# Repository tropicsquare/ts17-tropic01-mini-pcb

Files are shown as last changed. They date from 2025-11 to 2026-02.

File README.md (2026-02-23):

# TROPIC01 mini

This repository contains design files for the TROPIC01 minimal integration board TS17xx.
The ultimately small board for any purpose. Just control pins with power pins and that’s it. 

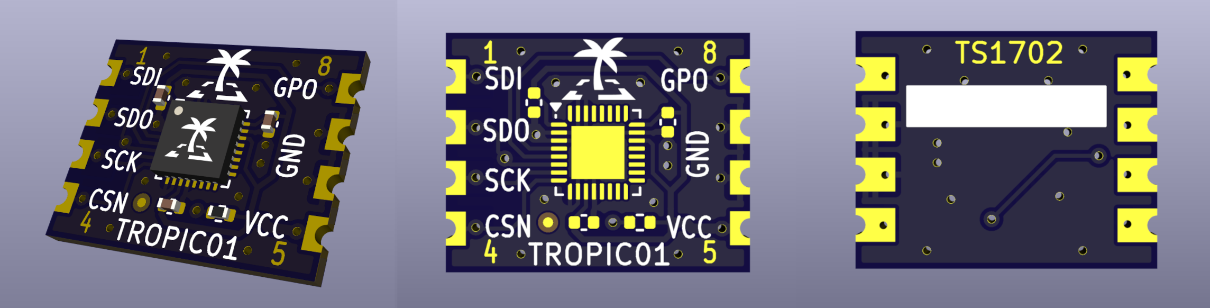
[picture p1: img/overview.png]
PCB view


## Project structure

* `*.kicad_pro` - KiCad project file
* `*.kicad_sch` - Schematic file
* `*.kicad_pcb` - PCB layout file
* `./gerber/` - Generated gerber data for PCB manufacturing
* `./bom/` - Bill of materials including order codes, interactive BOM and assembly coordinates
* `./img/` - Images (PCB renders)
* `*_schematics.pdf` - Exported schematic diagrams (latest version)

# Manufacturing instructions

## PCB

 - Number of cu layers: 2
 - Board Thickness: 1.0
 - Core: FR4
 - Size: 15.24 x 12 mm
 - Mask: Blue
 - Silkscreen: Yes (TOP)
 - Castellated holes

## Assembly

There are no any special requirements for C and R components.
Where not specified the R tolerance is 5% and C 20%.

# About TROPIC01

For more information about the TROPIC01 secure element, please see the official documentation:

*   [TROPIC01 Datasheet](https://github.com/tropicsquare/tropic01/tree/main/doc/datasheet)
*   [TROPIC01 Website](https://www.tropicsquare.com/tropic01)

## Getting Started

To interact with the TROPIC01 chip on Linux-based systems like Raspberry Pi OS and Ubuntu, we provide the 
[`libtropic-linux`](https://github.com/tropicsquare/libtropic-linux) repository, containing integration examples 
of our platform-independent SDK, [`libtropic`](https://github.com/tropicsquare/libtropic).

 > [!IMPORTANT]
 > Before you start with various examples, we strongly recommend to do two things first:
 > * Read CHIP ID and TROPIC01's firmware versions and **save printed output for future reference**
 > * Update TROPIC01's both internal firmware to latest version.

In [`libtropic-linux`](https://github.com/tropicsquare/libtropic-linux) repository, you can find specific instruction for both operations based on hardware you use.

### Command line utility

Once you saved results of `show_chip_id_and_fw_ver` example (for future reference) and after your chip is updated with `fw_update` example, 
you can test our command line application. Check out [`libtropic-util`](https://github.com/tropicsquare/libtropic-util) repository, 
you can find there specific instruction based on hardware you use.

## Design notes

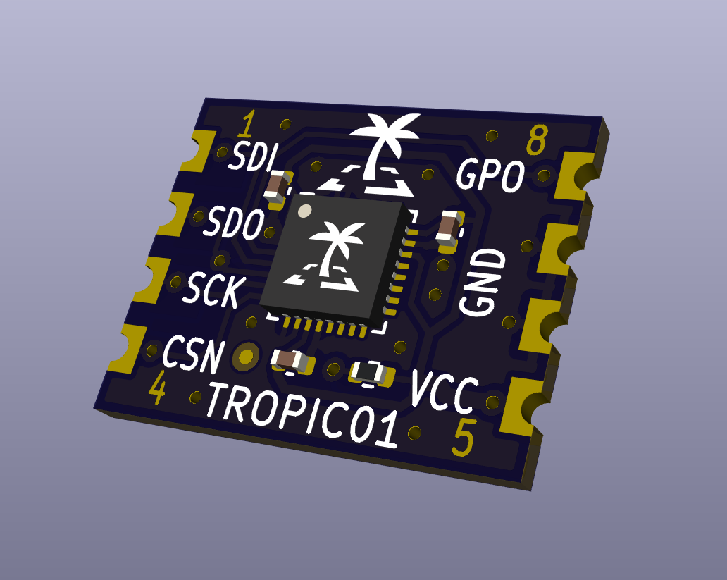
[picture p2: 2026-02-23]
img/angle.png

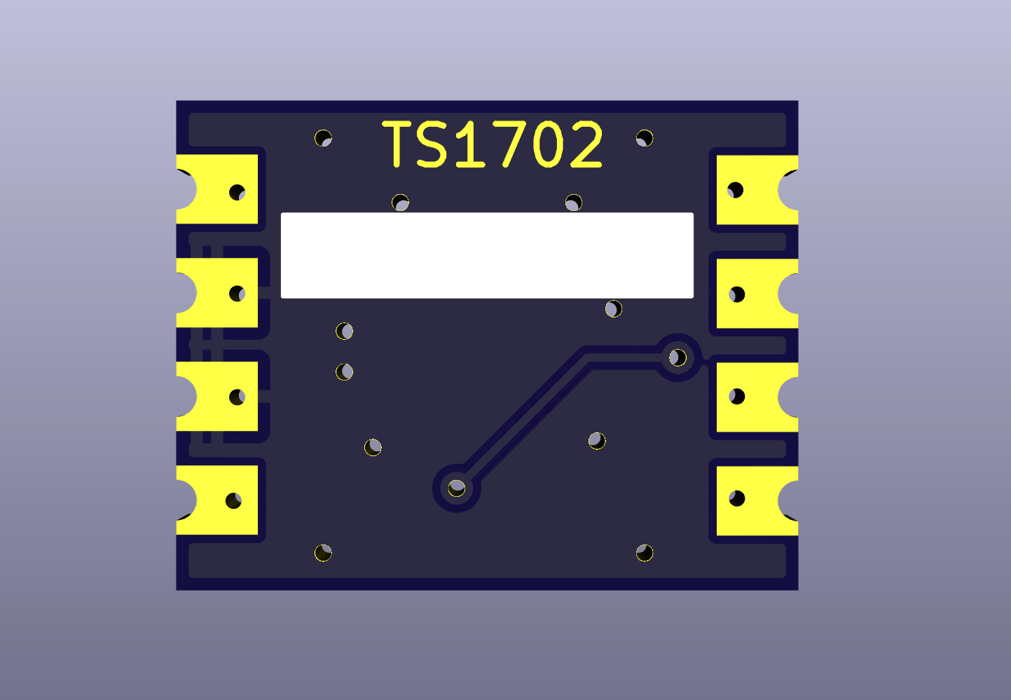
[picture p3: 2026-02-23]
img/bot.png

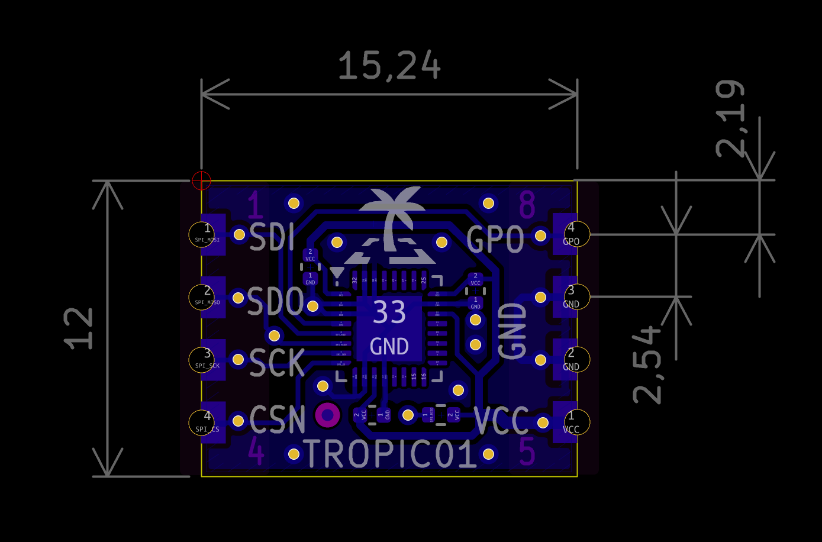
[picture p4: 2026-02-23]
img/dimensions.png

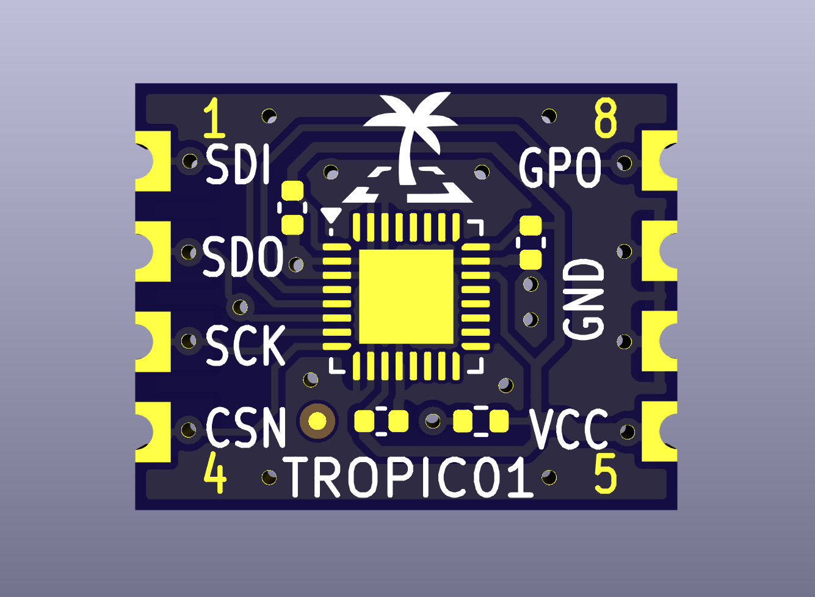
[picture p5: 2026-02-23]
img/top.png

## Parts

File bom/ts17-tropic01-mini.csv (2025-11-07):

Reference | Qty | Value | DNP | Exclude from BOM | Exclude from Board | Footprint | Datasheet | OC_MOUSER
C1,C2,C3 | 3 | 100n |  |  |  | Capacitor_SMD:C_0402_1005Metric | ~ | 80-C0402C104M4RAUTO
IC1 | 1 | TROPIC01_chip |  |  |  | tropic01_chip:QFN-32-1EP_4x4mm_P0.4mm_EP2.65x2.65mm |  | T101
R1 | 1 | 47k |  |  |  | Resistor_SMD:R_0402_1005Metric | ~ | 652-CR0402JW-473GLF

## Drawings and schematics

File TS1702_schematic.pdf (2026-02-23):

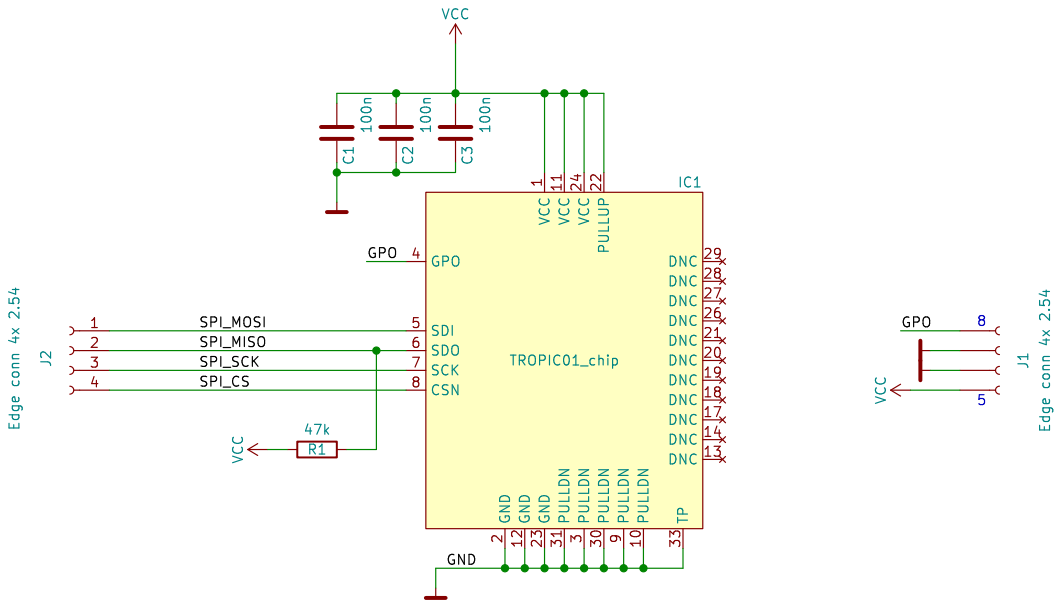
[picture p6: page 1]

1 GND 23 VCC 11 PULLDN 31 VCC 24 PULLDN

9 PULLDN 10 TP 33 DNC 29 DNC 28 DNC 27 DNC 26 DNC 21 DNC 20 DNC 19 DNC 18 DNC 17 DNC 14 DNC 13

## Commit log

2025-11-07 Initial commit. Add schematic and PCB project file.
    [ts17-tropic01-mini.kicad_pcb, ts17-tropic01-mini.kicad_sch]
2025-11-07 Add manufacturing output files (gerber data and BOM)
    [ts17-tropic01-mini-B_Cu.gbr, ts17-tropic01-mini-B_Mask.gbr, ts17-tropic01-mini-Edge_Cuts.gbr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]
2025-11-07 Change silkscreen text "+" to "VCC"
    [ts17-tropic01-mini-B_Cu.gbr, ts17-tropic01-mini-B_Mask.gbr, ts17-tropic01-mini-Edge_Cuts.gbr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]
2025-11-12 doc: Improve README.md and add LICENSE file
    [ts17-tropic01-mini-pos.csv]
2026-02-19 feat: Add silkscreen placeholder rectangle
    [ts17-tropic01-mini.kicad_pcb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]
2026-02-23 refactor: Change size to match 2,54mm spacing (14mm to 15.24mm)
    [ETR01APP-132]
    [ts17-tropic01-mini.kicad_pcb, ts17-tropic01-mini.kicad_sch]
2026-02-23 doc: Update images and manufacturing data
    [ts17-tropic01-mini-B_Cu.gbr, ts17-tropic01-mini-B_Mask.gbr, ts17-tropic01-mini-B_Silkscreen.gbr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]
